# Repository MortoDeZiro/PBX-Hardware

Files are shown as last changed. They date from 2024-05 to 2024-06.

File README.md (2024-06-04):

<!DOCTYPE html>
<html lang="en">
<head>
    <meta charset="UTF-8">
    <meta name="viewport" content="width=device-width, initial-scale=1.0">
  
</head>
<body>
    <h1>PBX Hardware</h1>
<p>This device is comprised of off-the-shelf components and 3D-printed parts.<br></p>
<p>This device is meant to replace a keyboard for gaming. It was designed to feel more like a handheld controller than a keyboard, to cause less strain on the hand and wrist, and to make it easier to find the function or action you're looking for.<br></p>
    <p>These are the early stages of documenting and releasing information about the project to the public.</p>
    <p>I welcome any help from contributors with a positive frame of mind who want to help the project along.</p>
    <p>I realize that these documents seem incomplete and not of the best quality but I will endeavor to improve and complete the project over time.</p>
 <p>Overall cost of the project is around $70.00.</p>
<br>
<br>

<h1>Do it yourself instructions</h1><br/>
  <p>Read the Guide to building a basic version of the controller here:  </p>
 <a href="https://github.com/MortoDeZiro/PBX-Hardware/blob/main/Building%20Documentation/DIY%20Guide%20for%20the%20PBX%20Gaming%20controller.pdf" target="_blank" rel="noreferrer noopener">DIY Guide</a>
<br><br/>
  <p>Links to all required documentation for the build here:</p>
<a href="https://github.com/MortoDeZiro/PBX-Hardware/tree/main/Building%20Documentation" target="_blank" rel="noreferrer noopener">Building Documentation Folder"</a>
</body>
</html>

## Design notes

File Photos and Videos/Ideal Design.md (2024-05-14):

<!DOCTYPE html>
<html lang="en">
<head>
    <meta charset="UTF-8">
    <meta name="viewport" content="width=device-width, initial-scale=1.0">

https://github.com/MortoDeZiro/PBX-Hardware/assets/167939056/4a8dbcbb-1012-468b-9cce-5a67283cd1d3

</head>
<body>
  

</body>
</html>

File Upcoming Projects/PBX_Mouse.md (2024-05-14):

<!DOCTYPE html>
<html lang="en">
<head>
    <meta charset="UTF-8">
    <meta name="viewport" content="width=device-width, initial-scale=1.0">
  
</head>
<body>
    <h1>PBX Mouse</h1>

https://github.com/MortoDeZiro/PBX-Hardware/assets/167939056/8517169d-c731-47d0-bc7b-0235ed9d90e2

</body>
</html>

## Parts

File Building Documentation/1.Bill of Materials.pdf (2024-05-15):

## Bill of Materials:

A: 1 x Arduino Micro with headers - $25.00

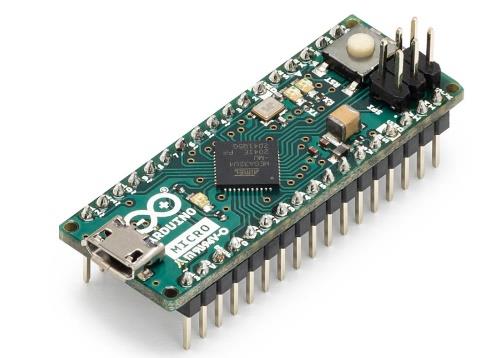
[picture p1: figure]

Make sure the Arduino you buy has the ATmega32U4 chip. --------------------------------------------------------------------------------------------------------------------------B: 1 x USB cable (USB to Micro or Mini, depending on the Arduino) - $2.00 - $4.00

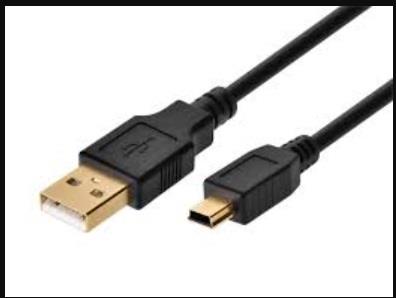
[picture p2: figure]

C: 3 meters of AWG24 cable (Extra Soft type is preferable) – Around $3.00 per meter

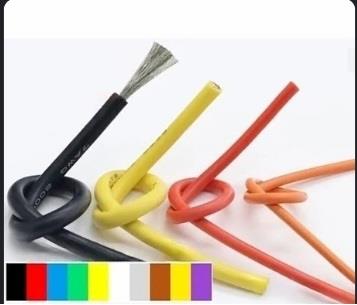
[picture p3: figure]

Will suggest getting black for “ground” wires, and other colors for 5V and pins.

D: 4 x Mechanical keyboard switches (of your choice.) - $2.00 each

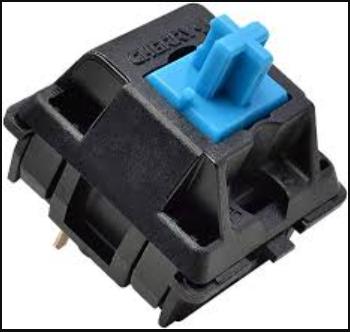
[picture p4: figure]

--------------------------------------------------------------------------------------------------------------------------E: 4 x keyboard switch keycaps - $0.50 - $1.00 each

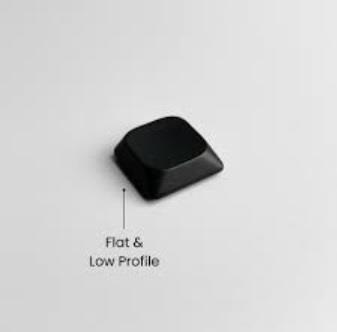
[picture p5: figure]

F: 1 /2 x 5-way switches (or 1 x 5-way switch and 1 x analog controller):

5way switch for movement: $5.00

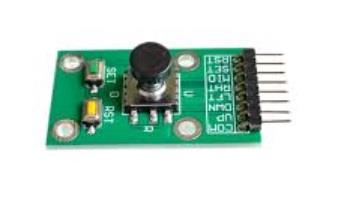
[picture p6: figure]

Analog for movement: $10.00

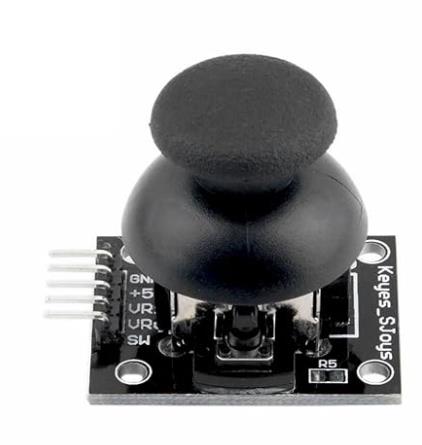
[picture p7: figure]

5way switch for function select: $5.00

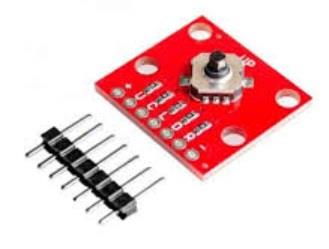
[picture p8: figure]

G: 30 X Female cable headers
Option - DIY: $1.00 for 16 (need a crimping tool)


Option – Ready-made: (need to cut, strip and solder to cable)


--------------------------------------------------------------------------------------------------------------------------2 terminal blocks – 1 x 5 pin + 1 x 3 Pin: Around $1.00 Each



Heat shrink tube – 2 meters of 3 mm: $0.50 per meter

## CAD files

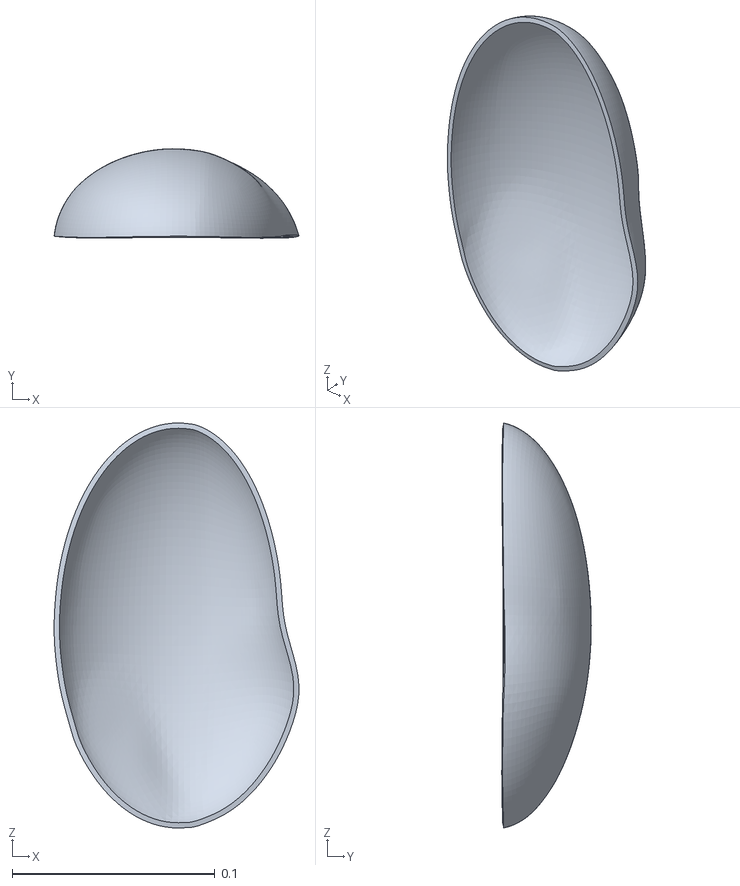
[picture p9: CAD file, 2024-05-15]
3D Print Files/PBXBasicPrint.obj
0.121 x 0.0442 x 0.2

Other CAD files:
3D Print Files/BasicPBXHousingPrint.stl

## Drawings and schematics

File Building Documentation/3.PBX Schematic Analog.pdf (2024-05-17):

## Analog Configuration

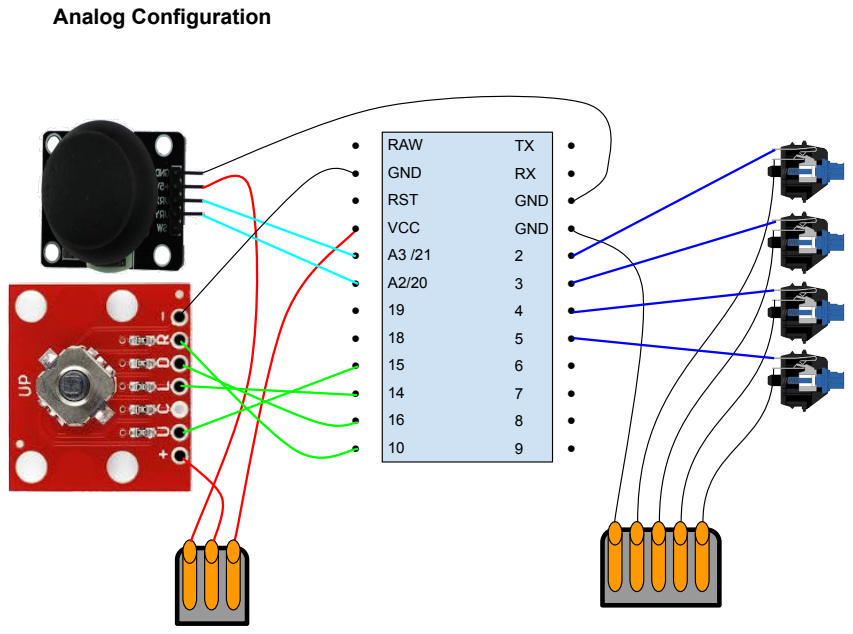
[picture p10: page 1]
GND; ● RAW; ● GND; ● RST; ● VCC

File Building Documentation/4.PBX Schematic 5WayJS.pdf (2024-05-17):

## 5 Way Switch Configuration

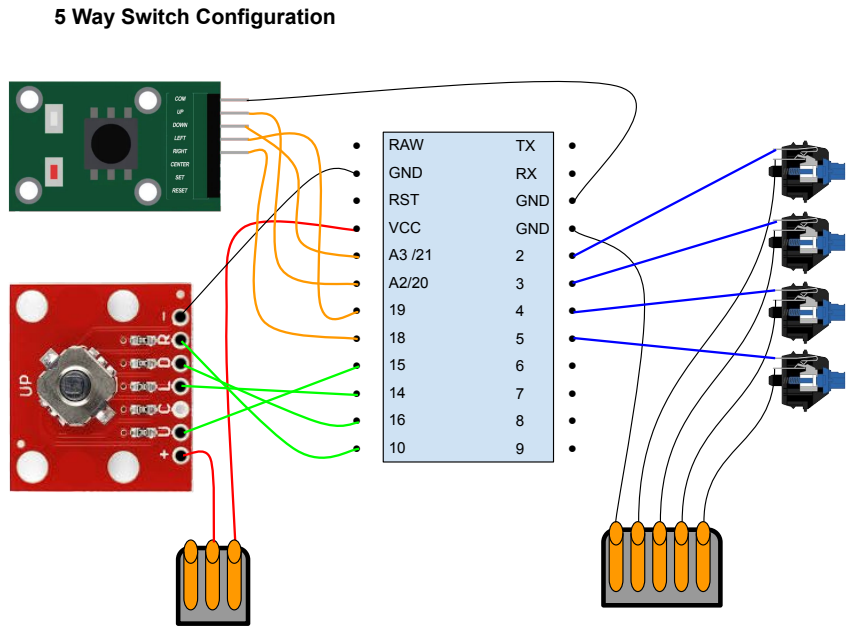
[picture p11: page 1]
GND; ● RAW; ● GND; ● RST; ● VCC

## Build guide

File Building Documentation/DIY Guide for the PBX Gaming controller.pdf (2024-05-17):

## DIY Guide for the PBX Gaming controller:

Note: This is a basic guide for building a basic version of the device. Experiment with comfort and complexity to upgrade and adjust the device to your comfort and play style.

All materials, code and schematics can be found in the Building Documentation folder: https://github.com/MortoDeZiro/PBX-Hardware/tree/main/Building%20Documentation

## Requirements:

(For more information, see Bill of Materials in the Building Documentation folder. )

1 x Arduino Pro Micro with headers
1 x USB cable (USB to Micro or Mini, depending on the Arduino)
AWG24 cable (Soft type is preferable)
4 x Mechanical keyboard switches (of your choice)
4 x keyboard switch keycaps
2 x 5-way switches ( or 1 5-way switch and 1 analog controller) 30 X Female cable headers
2 terminal blocks
Heat shrink tube
Lighter or heating device
Solder
Soldering Iron
Mini grinder
Super glue
Double sided tape
Marker
Computer
3D Printed Housing

Knowledge of: 3D printing, electronics, programming, soldering.

See pictures for reference here: https://github.com/MortoDeZiro/PBX-Hardware/blob/main/Building%20Documentation/Reference%20Photos.md (https://github.com/MortoDeZiro/PBX-Hardware/blob/main/Building%20Documentation/Reference%20Photos.md) --------------------------------------------------------------------------------------------------------------------------------------Step1:

Download the BasicPBXHousing.stl file here: https://github.com/MortoDeZiro/PBX-Hardware/tree/main/3D%20Print%20Files (https://github.com/MortoDeZiro/PBX-Hardware/tree/main/3D%20Print%20Files)

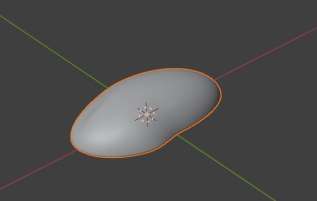
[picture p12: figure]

3D print it using the following measurements: (Can be adjusted according to your preference)

Length: 20 cm
Width: 11.8 cm
Height: 4.5 cm

Important! Mirror the file for a right-handed device.
(Most keyboard and mouse players play with their left hand on the keyboard.)
Step 2:

Determine where your grip feels comfortable and mark where you would like to place the mechanical keyboard switches.
(There is a slight indent on the back side of the device where the bottom of the palm sits comfortably.) Use the mini grinder to cut inserts to mount the switches.
Don’t glue them in yet, this can be done at the end once everything has been tested.

Determine and mark on the device where the analog (or 5-way switch) and (other) 5-way switch would be comfortable.
Cut or grind a medium-sized hole for the cables of the switches to pass to the Arduino.

See pictures for reference here: https://github.com/MortoDeZiro/PBX-Hardware/blob/main/Building%20Documentation/Reference%20Photos.md (https://github.com/MortoDeZiro/PBX-Hardware/blob/main/Building%20Documentation/Reference%20Photos.md)

Step 3:

Cut or grind a small hole at the bottom – front of the device for the USB cable.

Then mount the Arduino board (upside down with headers protruding outwards) and cable to the inside of the device using double sided tape.

Step 4:

Mount, with glue or double sided tape, the 2 terminals to the inside – back of the device. (One terminal will be used for all the ‘Ground’ wires and one for the 5V wires.)

Step 5:

(Each Keyboard switch has 2 wires: 1 that runs from keyboard switch to Arduino, and one that runs from keyboard switch to Ground terminal.)
(Use the pinout schematic for the Arduino, and the Arduino code to determine where each wire needs to go. Make a copy of the pinout schematic as it would be while upside down so that you can check where each wire needs to be connected.)

Measure and cut the wires from the pin of each keyboard switch to the pin of the Arduino, and the other pin on the keyboard switch to the Ground terminal:
leaving enough space to strip the wire to be soldered to the female header for the Arduino pins, for soldering the wire to the pin on the keyboard switch,
and the ground wire from the other pin of the keyboard switch to be placed into the Ground terminal.

Solder 1 wire for each switch to a female header, to be connected to the Arduino pins, with the other side to either pin on the keyboard switch.
Solder a second wire to the other pin and strip and tin the other side to be placed into the terminal.

Use Heat shrink tube to secure and strengthen connections where possible.

Don’t attach the pins to the headers yet, and don’t insert the wires into the terminals. This is to be done once everything is ready.
Step 6:

(The analog unit has 5 pins: One that will go to Ground terminal at the back, 2 to analog pins on the Arduino, one to a digital pin on the Arduino (optional), and one to the 5V terminal at the back.)

Measure, cut and solder female headers to the wires that go to the Arduino, and the analog unit’s pins, and strip and tin the sides of the wires that will go into the terminals at the back.

Alternatively, use a 5-way switch:
(The 5-way switch has 7 pins. 5 that will go to digital pins on the Arduino, one to the 5V terminal, and one to the Ground terminal at the back.)

Measure, cut and solder female headers to the wires that go to the Arduino and the 5-way switch unit’s pins, and strip and tin the sides of the wires that will go into the terminals at the back.

Step 7:

Prepare the 5-way switch’s wires:

(The 5-way switch has 7 pins. 5 that will go to digital pins on the Arduino, one to the 5V terminal, and one to the Ground terminal at the back.)

Measure, cut and solder female headers to the wires that go to the Arduino and the 5-way switch unit’s pins, and strip and tin the sides of the wires that will go into the terminals at the back.

Step 8:

Connect all wires according to the pinout schematic and code.

The Ground wires go to the terminal first, and from the terminal make a wire to go to the GND pin of the Arduino. Up to 2 wires can go in each terminal slot.
One GND pin can be used directly by either the analog or 5way switch.

5V wires go to the 5V terminal first and from there make a wire to the 5V pin on the Arduino.

Step 9: Coding and testing

Install the Arduino IDE:

If you haven’t already, download and install the Arduino IDE on your computer.

Connect the Arduino Board:

Connect your Arduino board to your computer using a USB cable.

Open the Arduino IDE:

Open the Arduino IDE that you installed in step 1.

Select the Correct Board:

Go to Tools > Board and choose the appropriate Arduino board you’re using (e.g., Arduino Uno, Arduino Pro Micro).

Select the Correct Port:

Go to Tools > Port and select the COM port to which your Arduino board is connected. If you’re unsure, check the available ports until you find the correct one.

Copy and Paste the Code:

Copy the provided code (in the Building Documentation Folder) and paste it into the Arduino IDE.

Verify the Code:

Click the Verify button (checkmark icon) to compile the code. Make sure there are no errors in the code.

Upload the Code:

Click the Upload button (right arrow icon) to upload the code to your Arduino board.

You’ll see messages in the console indicating the progress of the upload.

Test Your DIY Keyboard:

Press the buttons and switches on your keyboard to test if they trigger the corresponding keypresses (e.g., ‘a’, ‘s’, ‘d’, etc.).

Verify that the special keys (e.g., ‘r’, ‘j’, ‘c’, ‘n’, ‘Escape’, ‘Space’, ‘3’, ‘1’) also work as expected.

Customize and Enjoy:

Modify the code as needed to customize your keyboard layout, add more keys, or change the behavior.

Step 10:

Once everything works correctly, glue and/or tape everything securely to the housing.

Enjoy using your PBX keyboard!

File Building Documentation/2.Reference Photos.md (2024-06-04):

<!DOCTYPE html>
<html lang="en">
<head>
    <meta charset="UTF-8">
    <meta name="viewport" content="width=device-width, initial-scale=1.0">






</body>
</html>

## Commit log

2024-05-14 Create Basic Arduino code
2024-05-15 Update and rename Basic Arduino code to Arduino code 4WaySwitch
2024-05-15 Create Arduino code analog
2024-05-15 Update Arduino code analog
2024-05-15 Create Basic Housing Obj file
2024-05-15 Update and rename Basic Housing Obj file to Basic Housing Obj file.md
2024-05-15 Create 3D print Files
2024-05-15 Rename Arduino code analog to Arduino code Analog
2024-05-22 Rename Arduino code 4WaySwitch to Arduino code 5WaySwitch
2024-05-22 Update Arduino code 5WaySwitch
2024-06-04 Rename Bill of Materials.pdf to 1.Bill of Materials.pdf
2024-06-04 Rename PBX Schematic Analog.pdf to 3.PBX Schematic Analog.pdf
2024-06-04 Rename PBX Schematic 5WayJS.pdf to 4.PBX Schematic 5WayJS.pdf
2024-06-04 Rename Arduino code 5WaySwitch to 5.Arduino code 5WaySwitch
2024-06-04 Rename Arduino code Analog to 6.Arduino code Analog
